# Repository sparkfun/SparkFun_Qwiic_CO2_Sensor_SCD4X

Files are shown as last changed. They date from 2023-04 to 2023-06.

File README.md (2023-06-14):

SparkFun CO₂ Humidity and Temperature Sensor - SCD4x (Qwiic)
========================================

<table class="table table-hover table-striped table-bordered">
    <tr>
        <th class="text-center">
        </th>
        <th class="text-center">
        </th>
    </tr>
    <tr align="center">
        <td><a href="https://www.sparkfun.com/products/22395">SCD40</a></td>
        <td><a href="https://www.sparkfun.com/products/22396">SCD41</a></td>
    </tr>
    <tr align="center">
        <td><a href="https://www.sparkfun.com/products/22395">SparkFun CO₂ Humidity and Temperature Sensor - SCD40 (Qwiic)</a></td>
        <td><a href="https://www.sparkfun.com/products/22396">SparkFun CO₂ Humidity and Temperature Sensor - SCD41 (Qwiic)</a></td>
    </tr>
</table>

The SparkFun CO<sub>2</sub> Humidity and Temperature Sensor - SCD4x (Qwiic) features the SCD40 and SCD41 CO<sub>2</sub> sensors from Sensirion<sup>&copy;</sup>. The SCD4x sensors use Sensirion's PASens<sup>&reg;</sup> photoacoustic measurement system that combines narrow-band IR light and a microphone inside the sensing package capable of detecting concentrations from 0 to 40000 ppm with high accuracy. The SCD40 has best accuracy over 400-2000 ppm ±(50 ppm+5%) and the SCD41 has best accuracy over 400-5000 ppm ±(40 ppm+5%). The SCD4x have an integrated temperature and humidity CMos<sup>&reg;</sup> sensor to improve accuracy. For additional accuracy the SCD4x also accept ambient pressure readings!

Repository Contents
-------------------

* **/Documentation** - Data sheets, additional product information
* **/Hardware** - Eagle design files (.brd, .sch)
* **/Production** - Production panel files (.brd)
* **/docs** - Online documentation files

Documentation
--------------
* **[SparkFun SCD4x CO<sub>2</sub> Sensor Arduino Library](https://github.com/sparkfun/SparkFun_SCD4x_Arduino_Library)** - Arduino library for the SparkFun CO₂ Humidity and Temperature Sensor - SCD4x (Qwiic).
* **[Hookup Guide](https://sparkfun.github.io/SparkFun_Qwiic_CO2_Sensor_SCD4X)** - Basic hookup guide for the SparkFun Qwiic CO<sub>2</sub> Sensor - SCD4x.
* **[SparkFun Fritzing repo](https://github.com/sparkfun/Fritzing_Parts)** - Fritzing diagrams for SparkFun products.

Product Versions
----------------
* [SEN-22935](https://www.sparkfun.com/products/22395) - Qwiic CO<sub>2</sub> Sensor - SCD40
* [SEN-22396](https://www.sparkfun.com/products/22395) - Qwiic CO<sub>2</sub> Sensor - SCD41

Version History
---------------
* [SCD40 v10](https://www.sparkfun.com/products/22395) - Initial SparkFun release (SCD40)
* [SCD41 v10](https://www.sparkfun.com/products/22396) - Initial SparkFun release (SCD41)
* [SparkX SCD40 v01](https://www.sparkfun.com/products/18365) - Initial SparkX release (SCD40)
* [SparkX SCD41 v01](https://www.sparkfun.com/products/18366) - Initial SparkX release (SCD41)

License Information
-------------------

This product is _**open source**_!

Please review the LICENSE.md file for license information.

If you have any questions or concerns on licensing, please contact technical support on our [SparkFun forums](https://forum.sparkfun.com/viewforum.php?f=152).

Distributed as-is; no warranty is given.

- Your friends at SparkFun.

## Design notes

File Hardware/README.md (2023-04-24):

SparkFun <PRODUCT NAME> Design Files
=====================================

The .sch and .brd files hare are Eagle CAD schematic and PCB design files from SparkFun Electronics.
A freeware version of Autodesk Eagle can be found [here](https://www.autodesk.com/products/eagle/free-download).

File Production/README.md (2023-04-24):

SparkFun <PRODUCT NAME> Production Files
=========================================

These are the production files SparkFun uses for printing PCBs.

License Information
-------------------
This product is open source! 

The hardware is released under [Creative Commons ShareAlike 4.0 International](https://creativecommons.org/licenses/by-sa/4.0/).

Please use, reuse, and modify these files as you see fit. Please maintain attribution to SparkFun Electronics and release anything derivative under the same license.

Distributed as-is; no warranty is given.

- Your friends at SparkFun.

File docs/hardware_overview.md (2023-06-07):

---
icon: material/cog
---

Let's take a closer look at the SCD4X sensors and hardware on these sensor breakouts.

## SCD40 and SCD41 CO<sub>2</sub> Sensors

The SCD4x CO<sub>2</sub> sensors use Sensirion's PASense<sup>&trade;</sup>, a photoacoustic measurement system, to accurately measure CO<sub>2</sub> concentration using a combination of a narrow band of IR light and a microphone. The sensors also have a built-in humidity and temperatuer sensor using Sensirion's CMOSens<sup>&trade;</sup> technology to provide environmental data and compensate for environmental conditions in CO<sub>2</sub> measurement. For a detailed overview of the SCD4X sensors, refer to the [datasheet](./assets/component_documentation/Sensirion_CO2_Sensors_SCD4x_Datasheet.pdf).

<figure markdown>
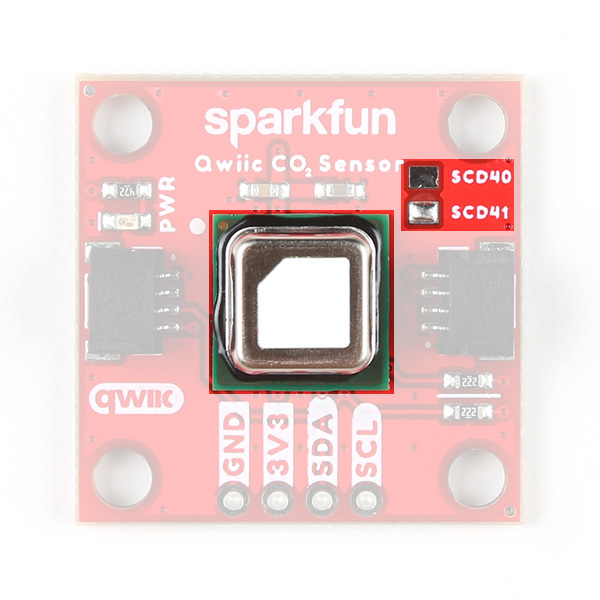
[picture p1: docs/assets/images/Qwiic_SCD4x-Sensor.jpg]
Highlighting the SCD4x sensor and version indicator

<figcaption markdown>Note: The PCB design is shared between the SCD40 and SCD41 and the version is indicated by the solder pad above the sensor.</figcaption>
</figure>

Now you may be curious as to just what photoacoustic measuring actually is. Photoacoustic measuring uses light (photo) and sound/vibrations (acoustic) in tandem to measure the the photoacoustic effect when energy is absorbed by particles (in the case of these sensors, CO<sub>2</sub> molecules). The SCD4X has an IR emitter with a filter to shine a specific IR light into the sensing area. CO<sub>2</sub> molecules inside the sensing area absorb energy from the emitted IR light and vibrate. The microphone inside the sensing area picks up this acoustic vibration and then this data is processed to report CO<sub>2</sub> concentration. This is just a quick and basic explanation of the photoacoustic process used in these sensors. For detailed information on Sensirion's PASens and CMOSens technology, refer to their [technology page](https://sensirion.com/products/technology).

The SCD4X sensors accept a supply voltage between <b>2.4V</b> to <b>5.5V</b> though they run on <b>3.3V</b> in standard Qwiic circuits. The sensors draw max of <b>205mA@3.3V</b> with an average draw of <b>18mA@3.3V</b> with periodic measurements in normal mode (<b>3.5mA@3.3V</b> in low power mode). While in Single Shot mode and taking one measurement every five minutes, the SCD41 draws only <b>0.5mA@3.3V</b>. 

Both sensors have identical operating characteristics outside of their ideal measurement ranges, measurement accuracy, and feature set. The SCD40's ideal measurement range is 400ppm to 2,000pm with an accuracy of &plusmn;50ppm + 5% of the reading and the SCD41 has an ideal measurement range of 400ppm to 5,000ppm with an accuracy of &plusmn;40ppm + 5% of the reading. The SCD41 also includes a single-shot mode for low power applications. The table below outlines the rest of the SCD4X's sensing parameters: 

<table>
    <tr>
        <th>Parameter</th>
        <th>Units</th>
        <th>Min</th>
        <th>Typ</th>
        <th>Max</th>
        <th>Notes</th>
    </tr>
    <tr>
        <td>CO<sub>2</sub> Output Range</td>
        <td>ppm</td>
        <td>0</td>
        <td>-</td>
        <td>40,000</td>
        <td></td>
    </tr>
    <tr>
        <td rowspan="2" style="vertical align middle">CO<sub>2</sub> Measurement Accuracy</td>
        <td rowspan="2" style="vertical align middle">ppm</td>
        <td>-</td>
        <td>&plusmn;(50 + 5%)</td>
        <td>-</td>
        <td>SCD40 accuracy</td>
    </tr>
    <tr>
        <td>-</td>
        <td>&plusmn;(40 + 5%)</td>
        <td>-</td>
        <td>SCD41 accuracy</td>
    </tr>
    <tr>
        <td>Humidity Range</td>
        <td>%RH</td>
        <td>0</td>
        <td>-</td>
        <td>100</td>
        <td></td>
    </tr>
    <tr>
        <td rowspan="2" style="vertical align middle">Humidity Accuracy</td>
        <td rowspan="2" style="vertical align middle">%RH</td>
        <td>-</td>
        <td>&plusmn;6</td>
        <td>-</td>
        <td>15&deg;C - 35&deg;C, 20%RH - 65%RH</td>
    </tr>
    <tr>
        <td>-</td>
        <td>&plusmn;9</td>
        <td>-</td>
        <td>-10&deg;C - 60 &deg;C, 0%RH - 100%RH</td>
    </tr>
    <tr>
        <td>Temperature Range</td>
        <td>&deg;C</td>
        <td>-10</td>
        <td>-</td>
        <td>60</td>
        <td></td>
    </tr>
    <tr>
        <td rowspan="2" style="vertical align middle">Temperature Accuracy</td>
        <td rowspan="2" style="vertical align middle">&deg;C</td>
        <td>-</td>
        <td>&plusmn;0.8</td>
        <td>-</td>
        <td>15&deg;C - 35&deg;C</td>
    </tr>
    <tr>
        <td>-</td>
        <td>&plusmn;1.5</td>
        <td>-</td>
        <td>-10&deg;C - 60&deg;C</td>
    </tr>
</table>

## Qwiic/I<sup>2</sup>C Interface

The boards route the SCD4X's I<sup>2</sup>C interface to a pair of Qwiic connectors as well as a 0.1"-spaced plated through-hole (PTH) header.

<figure markdown>
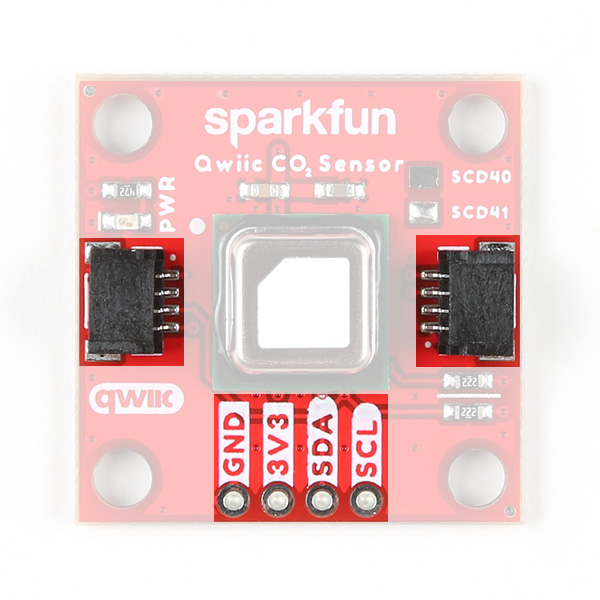
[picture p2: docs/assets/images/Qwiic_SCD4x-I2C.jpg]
Highlighting the Qwiic connectors and I2C PTH header.

</figure>

The SDC4X's has a 7-bit unshifted address of <b>0x62</b>. The I<sup>2</sup>C bus has a start up time after hard and soft resets of 1000ms and supports clock speeds up to 100kHz.

## LED

The sole LED on these boards is a red Power LED indicating when power is supplied to the board.

<figure markdown>
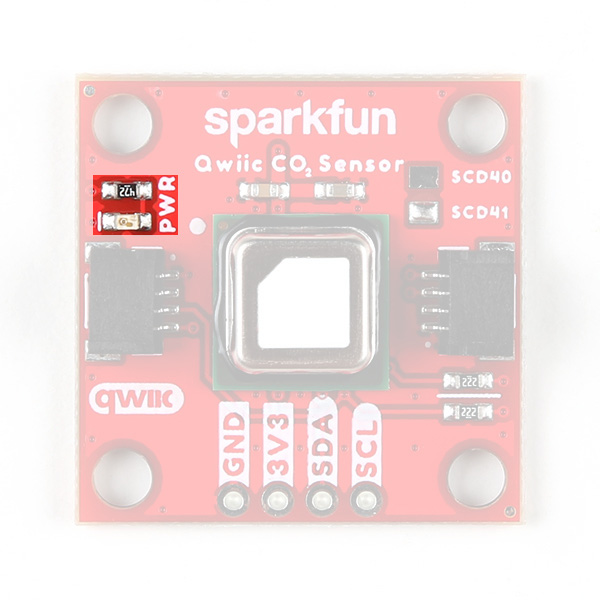
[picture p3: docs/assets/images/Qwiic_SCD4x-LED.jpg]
Highlighting the power LED

</figure>

## Solder Jumpers

The breakouts have a pair of solder jumpers labeled <b>PWR</b> and <b>I2C</b>. The PWR jumper completes the Power LED circuit. Open the jumper to disable the Power LED and reduce current draw of the board. The I2C jumper pulls the SDA/SCL lines to VCC (typically <b>3.3V</b>) through a pair of 2.2k&ohm; resistors. Open the jumper to disable the pullup resistors if needed.

<figure markdown>
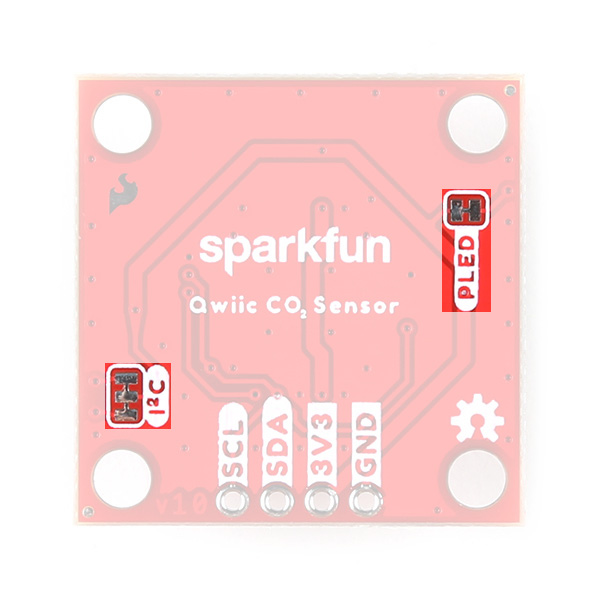
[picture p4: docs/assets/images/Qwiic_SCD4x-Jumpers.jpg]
Highlighting the solder jumpers

</figure>

## Board Dimensions

These breakouts match the 1" x 1" (25.4mm x 25.4mm) Qwiic breakout standard and have four mounting holes that fit a [4-40 screw](https://www.sparkfun.com/products/10453).

<figure markdown>
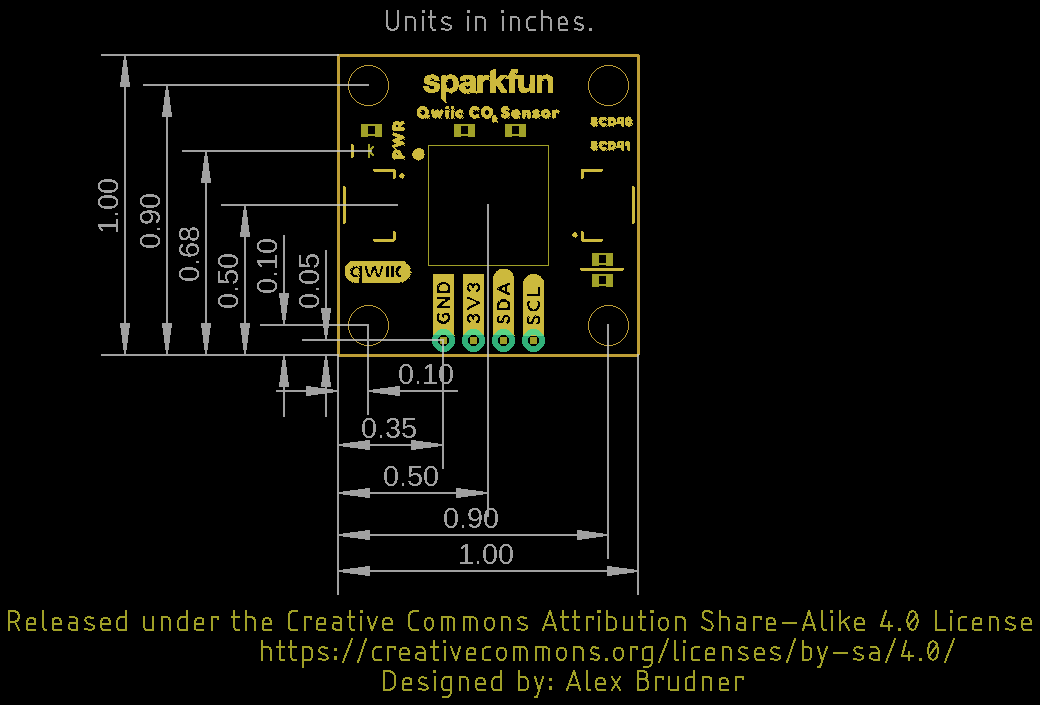
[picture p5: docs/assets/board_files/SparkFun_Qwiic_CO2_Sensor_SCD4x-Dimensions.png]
Board Dimensions

</figure>

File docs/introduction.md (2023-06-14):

---
icon: material/book-open-page-variant
---

The SparkFun CO<sub>2</sub>, Humidity and Temperature Sensor - SCD4X (Qwiic) breakouts feature the SCD40 and SCD41 CO<sub>2</sub> sensors from Sensirion<sup>&trade;</sup>. The SCD4X sensors use Sensirion&apos;s PASens<sup>&trade;</sup> photoacoustic measurement system that combines the use of narrow-band IR light and a microphone inside the sensing package that results in a high-quality sensor that measures CO<sub>2</sub> concentrations from 0 to 40,000ppm. The sensors also have an integrated humidity and temperature sensor to provide environmental conditions to improve accuracy. The SCD40 has the best accuracy from 400 to 2,000ppm and the SCD41 has the best accuracy from 400 to 5,000ppm.

These sensors also feature automatic self-calibration routines to automatically adjust to their sensing environments over seven day calibration period. For best results, Sensirion recommends taking continuous readings for at least one hour a day of 'fresh air' for the calibration period to complete.

<section class="grid cards col-2"markdown>

-	<a href="https://www.sparkfun.com/products/22395">
    <figure markdown>
	Product image
	</figure>
    </a>

    ---

    <a href="https://www.sparkfun.com/products/22395">
	**SparkFun CO<sub>2</sub> Humidity and Temperature Sensor - SCD40 (Qwiic)**<br>
	**SKU:** SEN-22395 
    </a>
	<center>
    [Purchase from SparkFun :fontawesome-solid-cart-plus:](https://www.sparkfun.com/products/22395){ .md-button .md-button--primary }
    </center>
    
-	<a href="https://www.sparkfun.com/products/22396">
    <figure markdown>
	Product image
	</figure>
    </a>

    ---

    <a href="https://www.sparkfun.com/products/22396">
    **SparkFun CO<sub>2</sub> Humidity and Temperature Sensor - SCD41 (Qwiic)**<br>
	**SKU:** SEN-22396
    </a>
	<center>
	[Purchase from SparkFun :fontawesome-solid-cart-plus:](https://www.sparkfun.com/products/22396){ .md-button .md-button--primary }
	</center>
    
</section>

<div style="text-align: center;">
    <iframe width="560" height="315" src="https://www.youtube.com/embed/sJqToow_iAg" title="YouTube video player" frameborder="0" allow="accelerometer; autoplay; clipboard-write; encrypted-media; gyroscope; picture-in-picture; web-share" allowfullscreen>
    </iframe>
</div>

In this guide we'll go over the details of the SCD4x sensors and other hardware present on these breakout boards, how to assemble it into a Qwiic circuit and how to use it with the SparkFun SCD4x Arduino Library.

## Required Materials

To follow along with this guide you will need a microcontroller to communicate with these SCD4X breakouts. Below are a few options that come Qwiic-enabled out of the box:

<div class="grid cards" markdown>

-   <a href="https://www.sparkfun.com/products/20168">

    <figure markdown>
    SparkFun Thing Plus - ESP32 WROOM (USB-C)
    </figure>
    </a>
    ---
    <a href="https://www.sparkfun.com/products/20168">
    **SparkFun Thing Plus - ESP32 WROOM (USB-C)**<br>
    DEV-20168
    </a>

-   <a href="https://www.sparkfun.com/products/18158">
    
    <figure markdown>
    SparkFun RedBoard Plus
    </figure>
    </a>
    ---
    <a href="https://www.sparkfun.com/products/18158">
    **SparkFun RedBoard Plus**<br>
    DEV-18158
    </a>

-   <a href="https://www.sparkfun.com/products/15574">
    
    <figure markdown>
    SparkFun Thing Plus - Artemis
    </figure>
    </a>
    ---
    <a href="https://www.sparkfun.com/products/15574">
    **SparkFun Thing Plus - Artemis**<br>
    DEV-18158
    </a>

-   <a href="https://www.sparkfun.com/products/15444">

    <figure markdown>
    SparkFun RedBoard Artemis
    </figure>
    </a>
    ---
    <a href="https://www.sparkfun.com/products/15444">**SparkFun RedBoard Artemis**<br>
    DEV-15444
    </a>
</div>

If your chosen microcontroller is not already Qwiic-enabled, you can add that functionality with one or more of the following items:

<div class="grid cards" markdown>

-   <a href="https://www.sparkfun.com/products/15081">

    <figure markdown>
    SparkFun Qwiic Cable Kit
    </figure>
    </a>
    ---
    <a href="https://www.sparkfun.com/products/15081">
    **SparkFun Qwiic Cable Kit**<br>
    KIT-15081
    </a>

-   <a href="https://www.sparkfun.com/products/14495">
    
    <figure markdown>
    SparkFun Qwiic Adapter
    </figure>
    </a>
    ---
    <a href="https://www.sparkfun.com/products/14495">
    **SparkFun Qwiic Adapter**<br>
    DEV-14495
    </a>

-   <a href="https://www.sparkfun.com/products/14352">
    
    <figure markdown>
    SparkFun Qwiic Shield for Arduino
    </figure>
    </a>
    ---
    <a href="https://www.sparkfun.com/products/14352">
    **SparkFun Qwiic Shield for Arduino**<br>
    DEV-14352
    </a>

-   <a href="https://www.sparkfun.com/products/16790">

    <figure markdown>
    SparkFun Qwiic Shield for Thing Plus
    </figure>
    </a>
    ---
    <a href="https://www.sparkfun.com/products/16790">
    **SparkFun Qwiic Shield for Thing Plus**<br>
    DEV-16790
    </a>
</div>

You will also need at least one Qwiic cable to connect your SCD4X breakout to your microcontroller:

<div class="grid cards" markdown>

-   <a href="https://www.sparkfun.com/products/17259">

    <figure markdown>
    Flexible Qwiic Cable - 100mm)
    </figure>
    </a>
    ---
    <a href="https://www.sparkfun.com/products/17259">
    **Flexible Qwiic Cable - 100mm**<br>
    PRT-17259
    </a>

-   <a href="https://www.sparkfun.com/products/17260">
    
    <figure markdown>
    Qwiic Cable - 50mm
    </figure>
    </a>
    ---
    <a href="https://www.sparkfun.com/products/17260">
    **Flexible Qwiic Cable - 50mm**<br>
    PRT-17260
    </a>

-   <a href="https://www.sparkfun.com/products/17257">
    
    <figure markdown>
    Flexible Qwiic Cable - 500mm
    </figure>
    </a>
    ---
    <a href="https://www.sparkfun.com/products/17257">
    **Flexible Qwiic Cable - 500mm**<br>
    PRT-17257
    </a>

-   <a href="https://www.sparkfun.com/products/17261">

    <figure markdown>
    Flexible Qwiic Cable - Female Jumper (4-pin)
    </figure>
    </a>
    ---
    <a href="https://www.sparkfun.com/products/17261">**Flexible Qwiic Cable - Female Jumper (4-pin)**<br>
    CAB-17261
    </a>
</div>

## Optional Materials

If you prefer a soldered connection or want to modify the solder jumpers on this board, you may need some of the products listed below:

<div class="grid cards" markdown align="center">

-   <a href="https://www.sparkfun.com/products/116">

    <figure markdown>
    Break Away Headers - Straight)
    </figure>
    </a>
    ---
    <a href="https://www.sparkfun.com/products/116">
    **Break Away Headers - Straight**<br>
    PRT-00116
    </a>

-   <a href="https://www.sparkfun.com/products/14681">
    
    <figure markdown>
    SparkFun Beginner Tool Kit
    </figure>
    </a>
    ---
    <a href="https://www.sparkfun.com/products/14681">
    **SparkFun Beginner Tool Kit**<br>
    TOL-14681
    </a>

-   <a href="https://www.sparkfun.com/products/9200">
    
    <figure markdown>
    Hobby Knife
    </figure>
    </a>
    ---
    <a href="https://www.sparkfun.com/products/9200">
    **Hobby Knife**<br>
    TOL-09200
    </a>

-   <a href="https://www.sparkfun.com/products/14579">

    <figure markdown>
    Chip Quik No-Clean Flux Pen - 10mL
    </figure>
    </a>
    ---
    <a href="https://www.sparkfun.com/products/14579">**Chip Quik No-Clean Flux Pen - 10mL**<br>
    CAB-14579
    </a>
</div>

## Suggested Reading

We designed this board for integration into SparkFun's Qwiic connect system.  Click on the banner below to learn more about the [SparkFun Qwiic Connect System](https://www.sparkfun.com/qwiic).

<div style="text-align: center">
<table>
  <tr>
   <td>
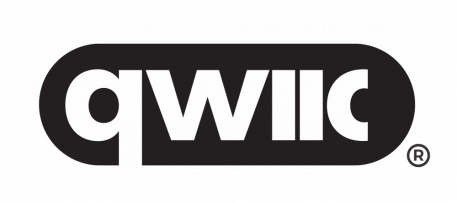
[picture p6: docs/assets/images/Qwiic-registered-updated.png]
Qwiic Connect System Click to learn more about the Qwiic Connect System!
   <div style="text-align: center"></div>
   </td>
  </tr>
  <tr>
    <td><div style="text-align: center"><i><a href="https://www.sparkfun.com/qwiic">Qwiic Connect System</a></i></div></td>
  </tr>
</table>
</div>

Before getting started with this Hookup Guide, you may want to read through the tutorials below if you are not familiar with the concepts covered in them or want a refresher. If you are using either of the Qwiic Shields linked above, we recommend reading through their respective Hookup Guides before continuing with this tutorial:

<div class="grid cards hide col-4" markdown align="center">

-   <a href="https://learn.sparkfun.com/tutorials/8">
    <figure markdown>
    Serial Communication
    </figure>
    </a>
    <a href="https://learn.sparkfun.com/tutorials/8">**Serial Communication**
    </a>

-   <a href="https://learn.sparkfun.com/tutorials/82">
    <figure markdown>
    I2C
    </figure>
    </a>
    <a href="https://learn.sparkfun.com/tutorials/82">**I2C**
    </a>

-   <a href="https://learn.sparkfun.com/tutorials/62">
    <figure markdown>
    Logic Levels
    </figure>
    </a>
    <a href="https://learn.sparkfun.com/tutorials/62">**Logic Levels**
    </a>

-   <a href="https://learn.sparkfun.com/tutorials/61">
    <figure markdown>
    Installing Arduino IDE
    </figure>
    </a>
    <a href="https://learn.sparkfun.com/tutorials/61">**Installing Arduino IDE**
    </a>

-   <a href="https://learn.sparkfun.com/tutorials/15">
    <figure markdown>
    Installing an Arduino Library
    </figure>
    </a>
    <a href="https://learn.sparkfun.com/tutorials/15">**Installing an Arduino Library**
    </a>

-   <a href="https://learn.sparkfun.com/tutorials/112">
    <figure markdown>
    Serial Terminal Basics
    </figure>
    </a>
    <a href="https://learn.sparkfun.com/tutorials/112">**Serial Terminal Basics**
    </a>

-   <a href="https://learn.sparkfun.com/tutorials/664">
    <figure markdown>
    How to Work with Jumper Pads and PCB Traces
    </figure>
    </a>
    <a href="https://learn.sparkfun.com/tutorials/664">**How to Work with Jumper Pads and PCB Traces**
    </a>

-   <a href="https://learn.sparkfun.com/tutorials/684">
    <figure markdown>
    Qwiic Shield for Arduino & Photon Hookup Guide
    </figure>
    </a>
    <a href="https://learn.sparkfun.com/tutorials/684">**Qwiic Shield for Arduino & Photon Hookup Guide**
    </a>

-   <a href="https://learn.sparkfun.com/tutorials/1107">
    <figure markdown>
    Qwiic Shield for Thing Plus Hookup Guide
    </figure>
    </a>
    <a href="https://learn.sparkfun.com/tutorials/1107">**Qwiic Shield for Thing Plus Hookup Guide**
    </a>
</div>

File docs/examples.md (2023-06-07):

The SparkFun SCD4X Arduino Library includes several examples to start receiving CO<sub>2</sub> concentration, temperature and humidity data from the SCD4X. Let's take a closer look at a few of the examples included with the library.

## Example 1 - Basic Readings

The first example in the library demonstrates how to initialize the SCD4X on the I<sup>2</sup>C bus to poll data from the sensor using periodic measurements every five seconds. Open the example by navigating to **File** > **Examples** > **SparkFun SCD4x Arduino Library** > **Example1_BasicReadings**. Alternatively, you can copy the code below into a blank Arduino sketch:

??? "Example 1 Arduino Code"
	```
	--8<-- "https://raw.githubusercontent.com/sparkfun/SparkFun_SCD4x_Arduino_Library/main/examples/Example1_BasicReadings/Example1_BasicReadings.ino"
	```

Select your Board/Port and click the "Upload" button. Once the code finishes uploading, open up a [Serial Monitor](https://learn.sparkfun.com/tutorials/terminal-basics) and check the output. You should see CO<sub>2</sub>, temperature and humidity data print out every 5 seconds:

<figure markdown>
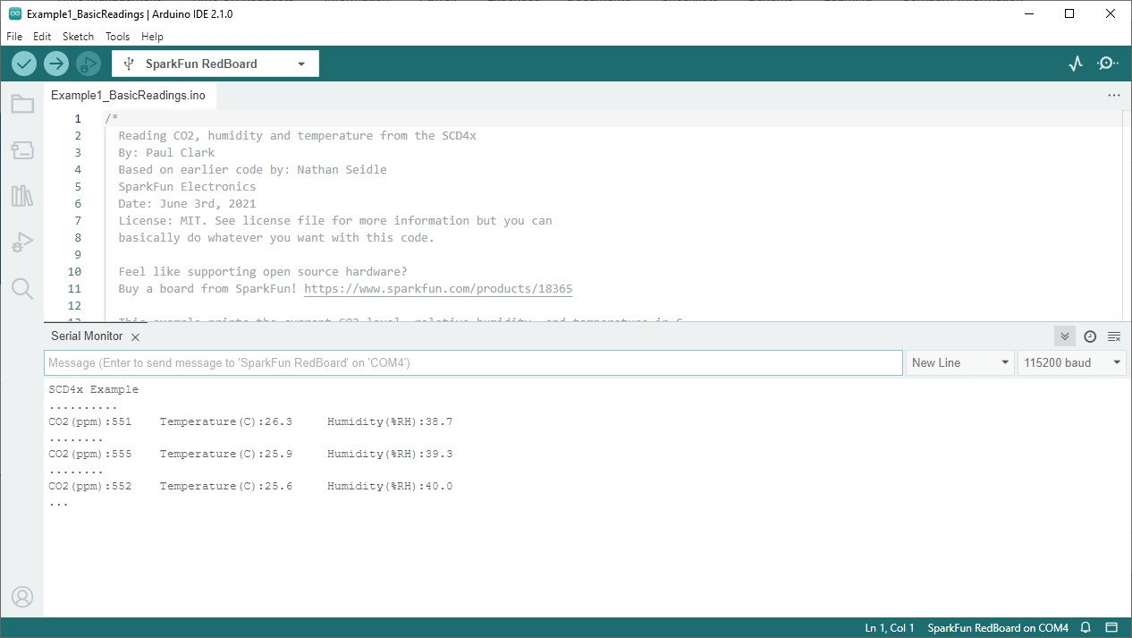
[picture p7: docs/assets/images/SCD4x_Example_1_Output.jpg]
Highlighting the power LED

</figure>

## Example 2 - Low Power Readings

The second example demonstrates how to configure the SCD4X to disable periodic measurements and enable low-power mode. This sets the SCD4x to take measurements every 30 seconds. Open the example in Arduino or copy the code below into a blank sketch:

??? "Example 2 Arduino Code"
    ```
	--8<-- "https://raw.githubusercontent.com/sparkfun/SparkFun_SCD4x_Arduino_Library/main/examples/Example2_LowPowerReadings/Example2_LowPowerReadings.ino"
	```
After uploading, open the serial monitor and you should see data print out every second though it should remain static for the 30 seconds between measurements.

## Example 6 - Signal Compensation

Example six shows how to input custom compensation values for temperature, altitude and ambient pressure. The code stops periodic measurements while the values are stored. These values are stored in the sensor's RAM by default but can be stored in EEPROM. When stored in RAM, the values reset if <code>reInit</code> is called or on a power cycle. After the settings are stored, the code reinitializes periodic measurements and prints out data for CO<sub>2</sub>, temperature, and humidity.

??? "Example 6 Arduino Code"
    ```
	--8<-- "https://raw.githubusercontent.com/sparkfun/SparkFun_SCD4x_Arduino_Library/main/examples/Example6_SignalCompensation/Example6_SignalCompensation.ino"
	```

## Example 8 - SCD41 Single Shot

The eighth example demonstrates how to configure the SCD41 to operate in Single-Shot mode for maximum power efficiency. The code disables periodic measurements and enables single-shot measurements with the <code>measureSingleShot</code> function. The main loop waits for fresh data from the SCD41 and then prints out CO<sub>2</sub>, temperature, and humidity data whenever it is available.

??? "Example 6 Arduino Code"
    ```
	--8<-- "https://raw.githubusercontent.com/sparkfun/SparkFun_SCD4x_Arduino_Library/main/examples/Example8_SCD41SingleShot/Example8_SCD41SingleShot.ino"
	```

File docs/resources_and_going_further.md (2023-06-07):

For more information about the SCD4X and these breakouts, check out the links below:

* Schematics:
    * [SCD40](./assets/board_files/SparkFun_Qwiic_CO2_Sensor_SCD40.pdf)
    * [SCD41](./assets/board_files/SparkFun_Qwiic_CO2_Sensor_SCD41.pdf)
* Eagle Files:
    * [SCD40](./assets/board_files/SparkFun_Qwiic_CO2_Sensor_SCD40.zip)
    * [SCD41](./assets/board_files/SparkFun_Qwiic_CO2_Sensor_SCD41.zip)
* [Board Dimensions](./assets/board_files/SparkFun_Qwiic_CO2_Sensor_SCD4x-Dimensions.png)
* [Datasheet](./assets/component_documentation/Sensirion_CO2_Sensors_SCD4x_Datasheet.pdf) (SCD4X)
* [Qwiic Info Page](https://www.sparkfun.com/qwiic)
* [SparkFun SCD4X Arduino Library](https://github.com/sparkfun/SparkFun_SCD4x_Arduino_Library)
* [Hardware GitHub Repo](https://github.com/sparkfun/SparkFun_Qwiic_CO2_Sensor_SCD4X)

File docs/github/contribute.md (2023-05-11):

# Help Improve the Experience!
Spot an improvement opportunity? Feel free to contribute to our open-source design and documentation. 

## Enhance our Documentation
All of this documentation can be modified by you! Please help us make it better.

* These pages are contained in the [`docs` folder](https://github.com/sparkfun/SparkFun_Qwiic_CO2_Sensor_SCD4X/tree/main/docs) of the [SparkFun Qwiic CO<sub>2</sub> Sensor - SCD4X](https://github.com/sparkfun/SparkFun_Qwiic_CO2_Sensor_SCD4X) repository.

### Submit a Correction
1. Fork this repo
2. Add your corrections or improvements to the markdown file
3. File a pull request with your changes, and enjoy making the ~~words~~ ~~worlds~~ world a better place.
	* Once received, the documentation specialist will automatically be notified.
	* We will review your suggested improvements to make sure they are correct and fit within our documentation standards.

## Upgrade our Hardware Design
All of our designs are open-source! Please help us make it better.

* Our board design files are contained in the [`Hardware` folder](https://github.com/sparkfun/SparkFun_Qwiic_CO2_Sensor_SCD4X/tree/main/Hardware) of the [SparkFun Qwiic CO<sub>2</sub> Sensor - SCD4X](https://github.com/sparkfun/SparkFun_Qwiic_CO2_Sensor_SCD4X) repository.

### Submit a Design Improvement
1. Fork this repo
2. Add your design modifications
3. File a pull request with your changes, and enjoy making the world a better place.
	* Once received, the engineer in charge of the original design will automatically be notified.
	* We will review your suggested upgrades, if they are within our board design standards and meet our product design requirements, we will flag these changes for our next board revision.
	
	!!! note
		Please note, that even if your suggestion is accepted, these changes may not be immediate. We may have to cycle through our current product inventory first.

## Contributors
Let's provide some recognition to those who have contributed to this project!

GitHub Contributors Image
<br>


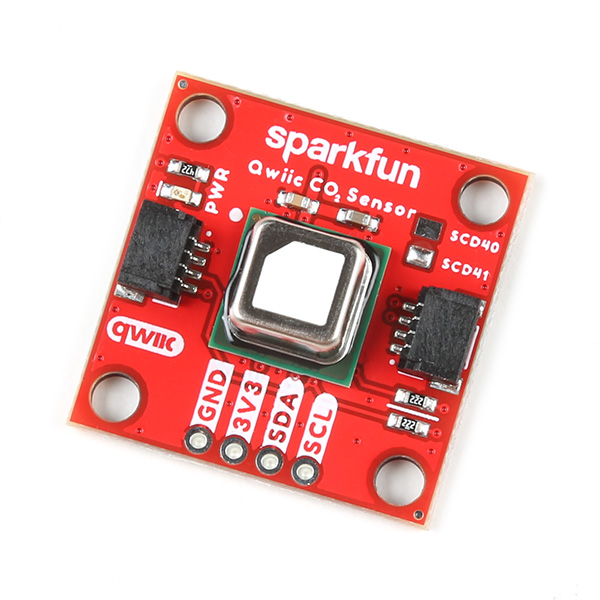
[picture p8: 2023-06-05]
site/assets/images/Qwiic_SCD4x-Thumb.jpg

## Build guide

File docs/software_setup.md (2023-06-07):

---
icon: simple/arduino
---

!!! attention
	If this is your first time using Arduino, please read through our tutorial on [installing the Arduino IDE](https://learn.sparkfun.com/tutorials/installing-arduino-ide). If you have not installed an Arduino library before, we recommend you check out our [installation guide](https://learn.sparkfun.com/tutorials/installing-an-arduino-library).

We've written an Arduino library for the SCD4X sensors to make it easy to get CO<sub>2</sub> data from these sensors along with other settings and features for these breakouts. Users can download the library through the Arduino Library Manager by searching for <b>"SparkFun SCD4x"</b> like the screenshot below shows:

<figure markdown>
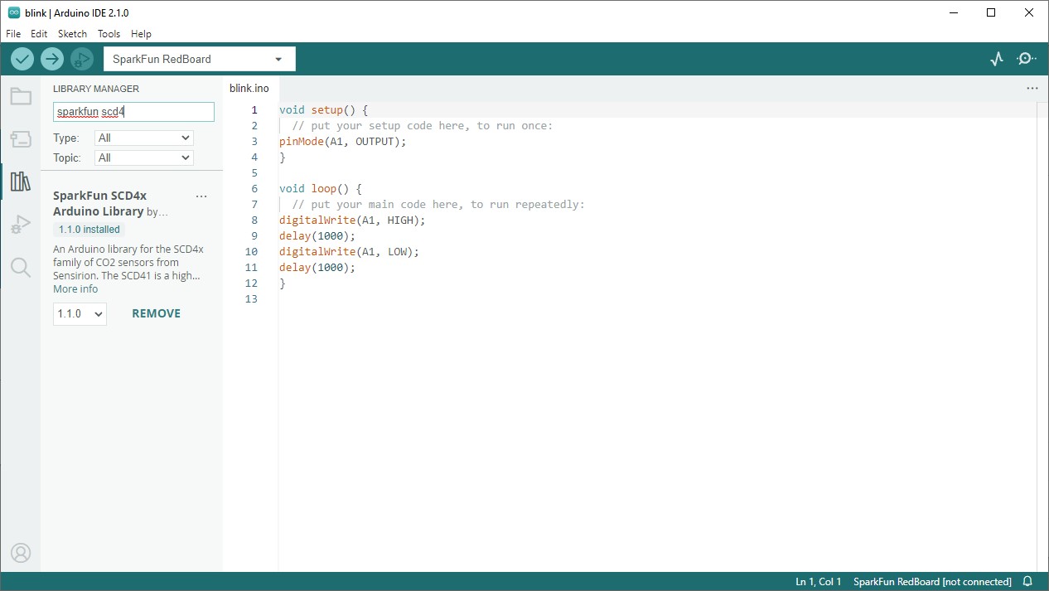
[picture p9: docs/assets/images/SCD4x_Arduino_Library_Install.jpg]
Highlighting the power LED

</figure>

Those who prefer to manually install it can download a ZIP of the library by clicking the button below:

<center>
[SparkFun SCD4x Arduino Library (ZIP)](https://github.com/sparkfun/SparkFun_SCD4x_Arduino_Library/archive/refs/heads/main.zip){ .md-button .md-button--primary }
</center>

With the library installed let's move on to looking at a few of the examples included in it.

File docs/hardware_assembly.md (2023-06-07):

---
icon: material/tools
---

Now that we're familiar with the SCD4X sensors and these breakouts, it's time to assemble it into a circuit.

## Qwiic Assembly

SparkFun's Qwiic system makes assembling a circuit a breeze. Simply plug the breakout into your chosen microcontroller with a Qwiic cable. After assembling your circuit, it should look similar to the photo below:

<figure markdown>
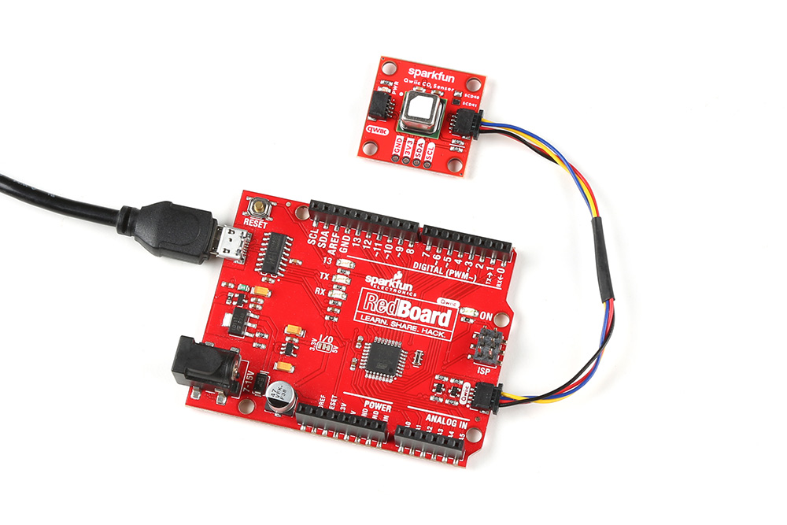
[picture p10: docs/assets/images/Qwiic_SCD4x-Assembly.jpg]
SparkFun SCD40 plugged into the RedBoard Qwiic

<figcaption markdown>SparkFun CO<sub>2</sub> Humidity and Temperature Sensor - SCD40 (Qwiic) plugged into the RedBoard Qwiic</figcaption>
</figure>

Reminder, for ideal results, make sure to fully calibrate the SCD4X by taking continuous measurements for one hour every day for seven days.

## Soldered Assembly

Those who prefer a traditional soldered assembly should solder wires or header pins to the PTH header on the side of the board. If you're not familiar with through-hole soldering or would like a refresher, take a look at our Through-Hole Soldering Tutorial:

<div class="grid cards" markdown align="center">

-   <a href="https://learn.sparkfun.com/tutorials/5">
    <figure markdown>
    How to Solder: Through-Hole Soldering
    </figure>
    </a>
    <a href="https://learn.sparkfun.com/tutorials/5">**How to Solder: Through-Hole Soldering**
    </a>

</div>

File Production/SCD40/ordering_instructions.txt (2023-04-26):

panel size, 169x117mm
PCB thickness, 1.6mm
number of layers, 2
soldermask color, Red
silkscreen color, White
oz copper, 1oz
finish, HASL lead free
stencils, top
pcs per panel, 24
min trace width, 0.1270mm / 0.0050in
min drill size, 0.3810mm / 0.0150in

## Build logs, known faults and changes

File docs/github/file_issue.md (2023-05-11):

# Did we make a mistake?

Spot something wrong? Please let us know. 

!!! attention
	This is not where customers should seek assistance on a product. If you require technical assistance or have questions about a product that is not working as expected, please head over to the [SparkFun Technical Assistance](https://www.sparkfun.com/technical_assistance) page for some initial troubleshooting.
    <center>
    [SparkFun Technical Assistance Page](https://www.sparkfun.com/technical_assistance){ .md-button .md-button--primary }
    </center>
    
    If you can't find what you need there, the [SparkFun Forums](https://forum.sparkfun.com/index.php) is a great place to search product forums and ask questions.
    
    !!! info "Account Registration Required"
        If this is your first visit to our forum, you'll need to create a [Forum Account](https://forum.sparkfun.com/ucp.php?mode=register) to search product forums and post questions.

## Discrepancies in the Documentation

All of this documentation can be modified by you! Please help us make it better.

* The documentation files for these pages are contained in the [`docs` folder](https://github.com/sparkfun/SparkFun_Qwiic_CO2_Sensor_SCD4X/tree/main/docs) of the [SparkFun Qwiic CO<sub>2</sub> Sensor - SCD4X](https://github.com/sparkfun/SparkFun_Qwiic_CO2_Sensor_SCD4X) repository.

### Spot something wrong?
If a section of the documentation is incorrect, please [open an issue](https://github.com/sparkfun/SparkFun_Qwiic_CO2_Sensor_SCD4X/issues) and let us know.

### Do you have a suggested correction?
1. With a GitHub account, fork this repo
2. Add your correction(s) or improvement(s) to the markdown file(s)
3. File a pull request with your changes, and enjoy making the ~~words~~ ~~worlds~~ world a better place.
	* Once received, the documentation specialist will automatically be notified.
	* We will review your suggested improvement(s) to make sure they are correct and fit within our documentation standards.

## Problems in the Hardware Design

All of our designs are open-source! Please help us make it better.

* Our board design files are contained in the [`Hardware` folder](https://github.com/sparkfun/SparkFun_Qwiic_CO2_Sensor_SCD4X/tree/main/Hardware) of the [SparkFun Qwiic CO<sub>2</sub> Sensor - SCD4X](https://github.com/sparkfun/SparkFun_Qwiic_CO2_Sensor_SCD4X) repository.

### Does something not make sense?
If part of the design is confusing, please [open an issue](https://github.com/sparkfun/SparkFun_Qwiic_CO2_Sensor_SCD4X/issues) and let us know.

### Did we forget to include an important function of the board?
* Please keep in mind that we may intentionally exclude certain functions of the board to meet our product design requirements. *(For example, our Qwiic Micro boards are intended to fit on a small board layout and only use I<sup>2</sup>C communication; therefore, we may not have the SPI and interrupt pins available for users.)*
* If part of the board's functionality is missing, please [open an issue](https://github.com/sparkfun/SparkFun_Qwiic_CO2_Sensor_SCD4X/issues) and file a feature request.

### Do you wish to contribute directly to improving the board design?
1. With a GitHub account, Fork this repo
2. Add your design improvement(s)
3. File a pull request with your changes, and enjoy making the ~~words~~ ~~worlds~~ world a better place.
	* Once received, the engineer in charge of the original design will automatically be notified.
	* We will review your suggested improvement(s), if they are within our board design standards and meet our product design requirements, we will flag these changes for our next board revision. *(Please note, that even if your suggestion is accepted, these changes may not be immediate. We may have to cycle through our current product inventory first.)*

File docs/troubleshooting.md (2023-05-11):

!!! warning "Need Help?"
    If you need technical assistance or more information on a product that is not working as you expected, we recommend heading on over to the [SparkFun Technical Assistance](https://www.sparkfun.com/technical_assistanc) page for some initial troubleshooting.

    <center>
    [SparkFun Technical Assistance Page](https://www.sparkfun.com/technical_assistance){ .md-button .md-button--primary }
    </center>
    
    If you can't find what you need there, the [SparkFun Forums](https://forum.sparkfun.com/index.php) is a great place to search product forums and ask questions.
    
    !!! info "Account Registration Required"
        If this is your first visit to our forum, you'll need to create a [Forum Account](https://forum.sparkfun.com/ucp.php?mode=register) to post questions.

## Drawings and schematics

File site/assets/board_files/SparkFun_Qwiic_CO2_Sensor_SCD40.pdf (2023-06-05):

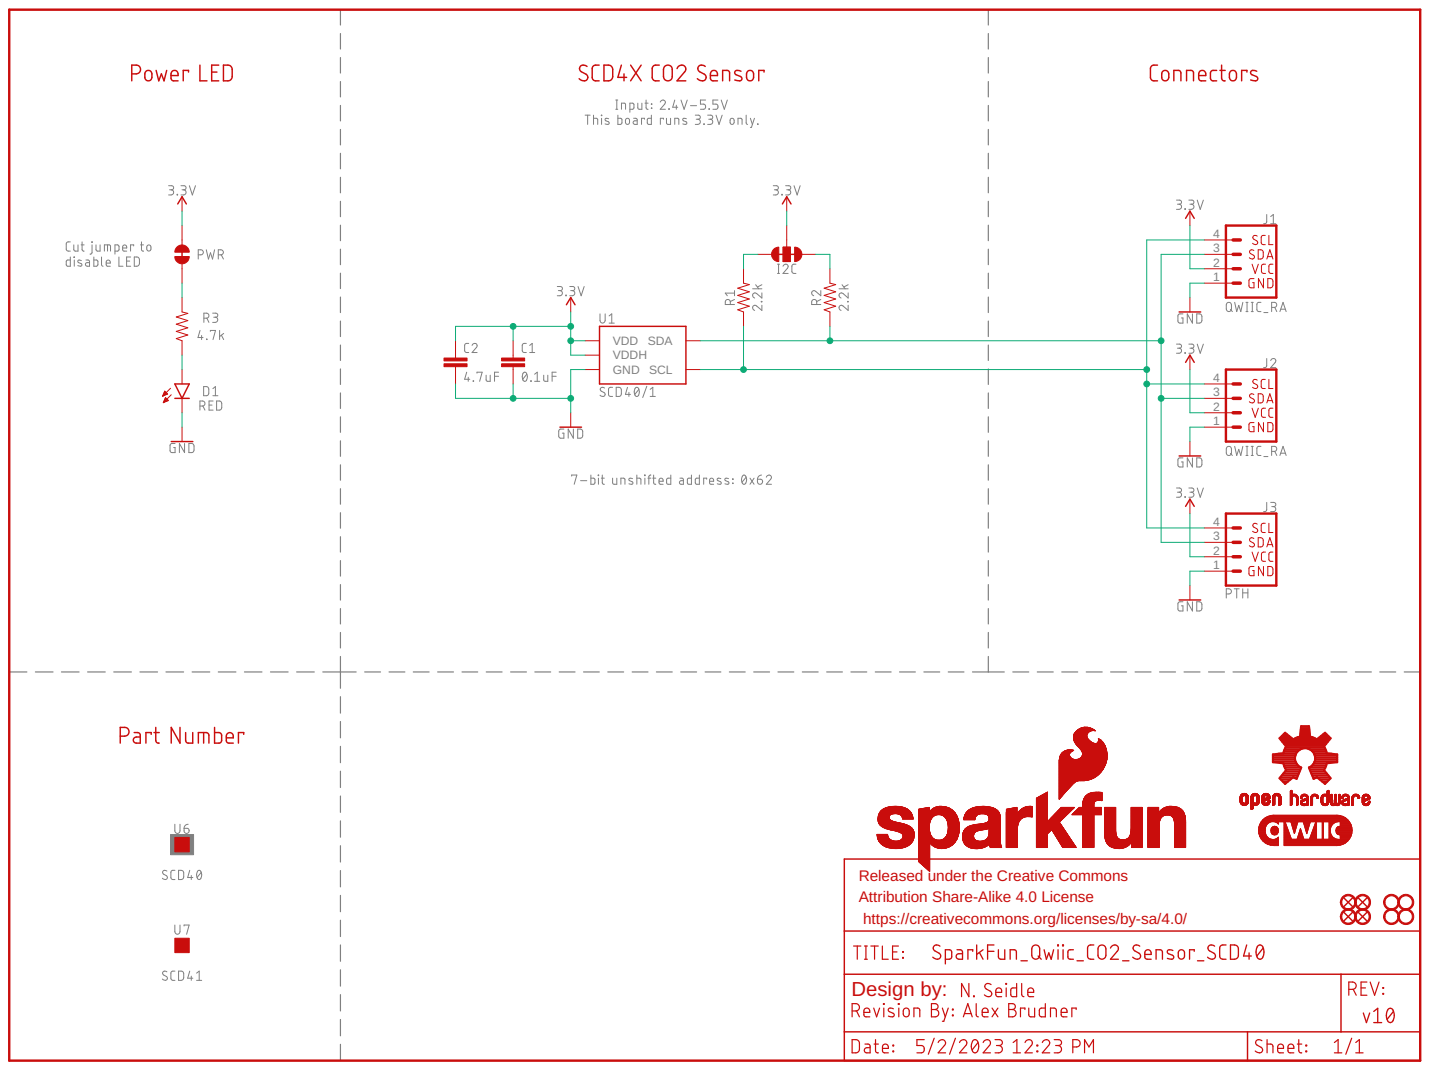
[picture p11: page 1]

Released under the Creative Commons Attribution Share-Alike 4.0 License

https://creativecommons.org/licenses/by-sa/4.0/

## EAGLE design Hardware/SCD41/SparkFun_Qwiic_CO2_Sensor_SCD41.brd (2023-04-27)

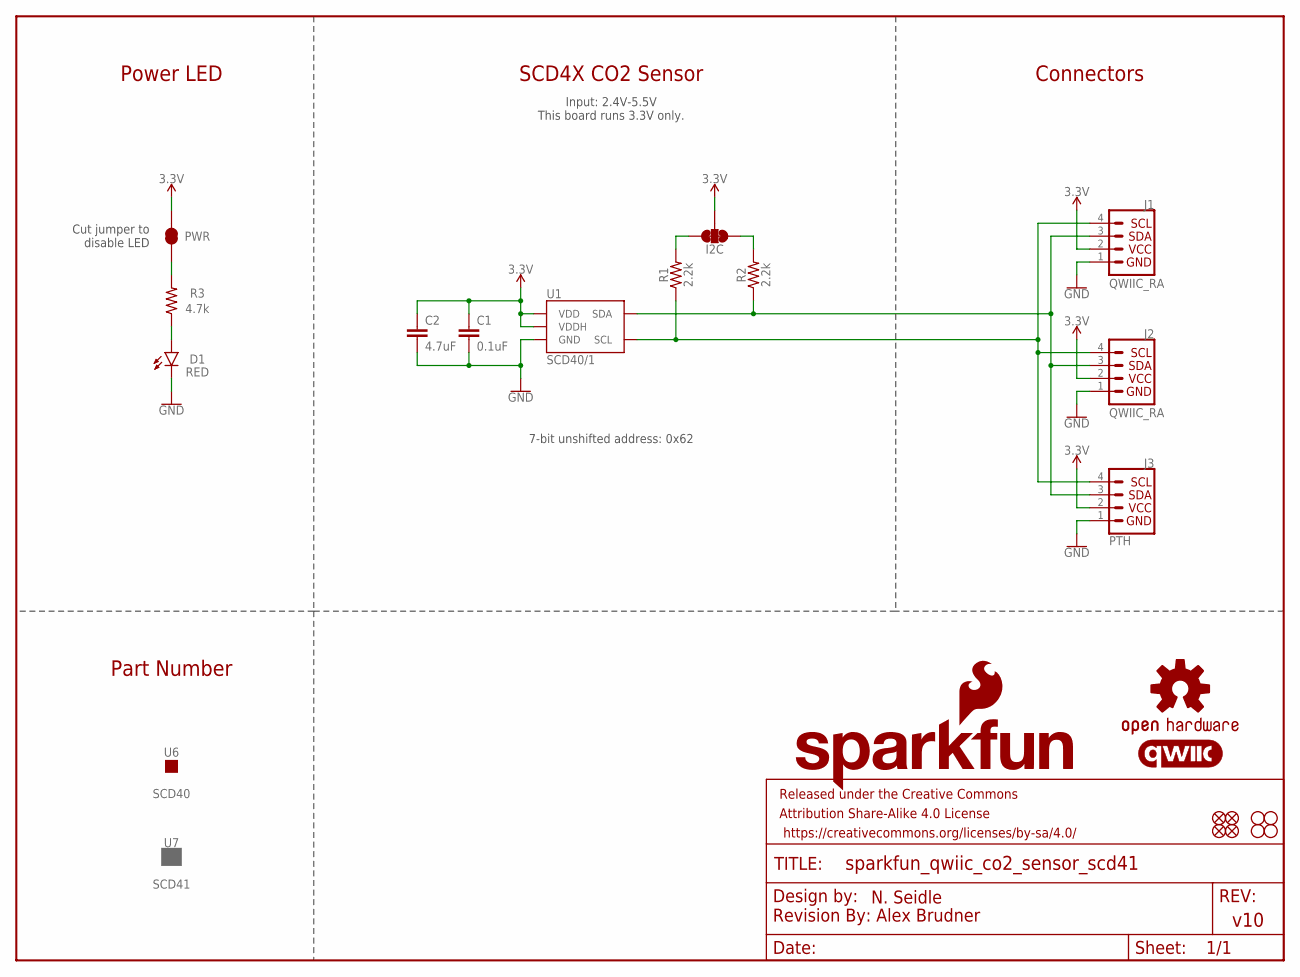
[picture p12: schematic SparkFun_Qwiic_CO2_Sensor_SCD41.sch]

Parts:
C1: 0.1uF; 0603
C2: 4.7uF; 0603
D1: RED; LED-0603
FD1, FD2, FD3, FD4: FIDUCIALUFIDUCIAL; FIDUCIAL-MICRO
FRAME1: FRAME-LETTER; CREATIVE_COMMONS
H1, H2, H3, H4: STAND-OFF
I2C: I2C; SMT-JUMPER_3_2-NC_TRACE_SILK
J1, J2: QWIIC_RA; JST04_1MM_RA
J3: PTH; 1X04_NO_SILK
LOGO1: QWIIC_LOGO_CONNECTOR; QWIIC_5.5MM
LOGO2: OSHW-LOGOS; OSHW-LOGO-S
LOGO3: SFE_LOGO_NAME_FLAMEBLANK; BLANK
PWR: PWR; SMT-JUMPER_2_NC_TRACE_SILK
R1, R2: 2.2k; 0603
R3: 4.7k; 0603
U1: SCD40/1; SCD4X
U6: SCD40; PRODUCT_IDENT_NO_NO-SILK
U7: SCD41; PRODUCT_IDENT_PASTE_NO-SILK

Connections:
3.3V: C1.1, C2.1, I2C.2, J1.2, J2.2, J3.2, PWR.2, U1.7 (VDD), U1.19 (VDDH)
GND: C1.2, C2.2, D1.C, J1.1, J2.1, J3.1, U1.6 (GND), U1.20 (GND), U1.CP (GND)
unnamed: I2C.1, R2.2
unnamed: I2C.3, R1.2
unnamed: PWR.1, R3.2
unnamed: D1.A, R3.1
SCL: J1.4, J2.4, J3.4, R1.1, U1.9 (SCL)
SDA: J1.3, J2.3, J3.3, R2.1, U1.10 (SDA)

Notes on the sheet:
Cut jumper to disable LED
SCD4X CO2 Sensor
Power LED
Connectors
Part Number
Input: 2.4V-5.5V This board runs 3.3V only.
7-bit unshifted address: 0x62

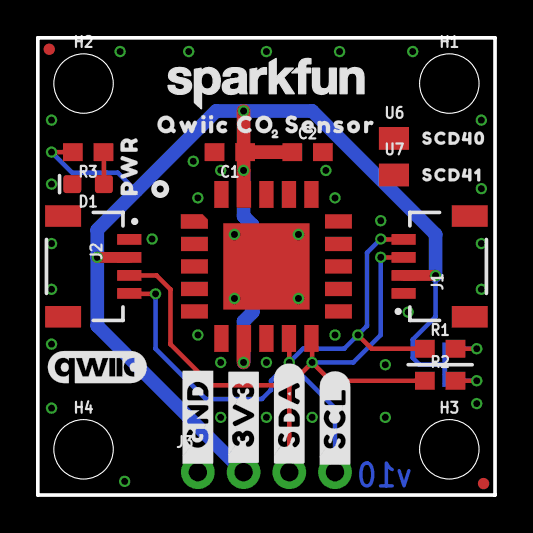
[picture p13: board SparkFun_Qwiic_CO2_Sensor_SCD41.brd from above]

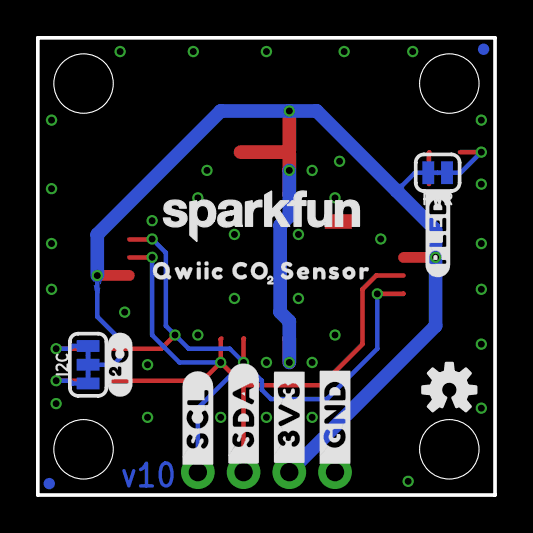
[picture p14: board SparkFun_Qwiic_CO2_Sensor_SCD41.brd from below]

Board: 2 copper layers, 25.4 x 25.4 mm, 49 parts (16 on the bottom side), 8 nets.

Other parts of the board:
U$1, U$18: #_GND#14
U$2, U$19: #_3V3#15
U$3, U$20: #_SDA#15
U$4, U$21: #_SCL#16
U$5, U$12: SFE_LOGO_NAME_.1
U$6: SCD414140404021
U$7: SCD40414140404022
U$8, U$13: QWIIC_CO0
U$9, U$14: SENSOR0
U$10, U$15: 20
U$11: SFE_LOGO_FLAME_STOP_.1
U$16: #PLED#21
U$17: #I�C#0
U$22: ORDERING_INSTRUCTIONS
U$23: PWR0

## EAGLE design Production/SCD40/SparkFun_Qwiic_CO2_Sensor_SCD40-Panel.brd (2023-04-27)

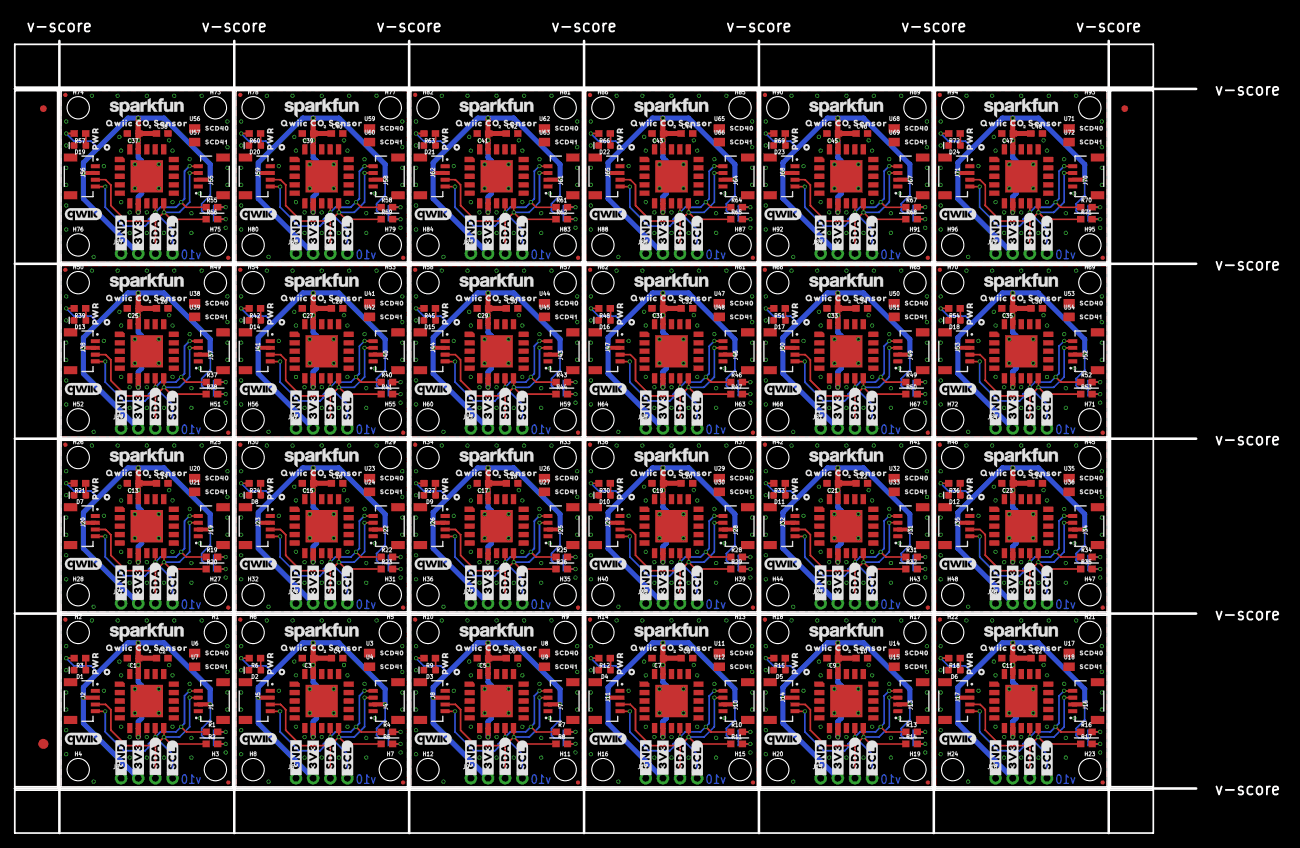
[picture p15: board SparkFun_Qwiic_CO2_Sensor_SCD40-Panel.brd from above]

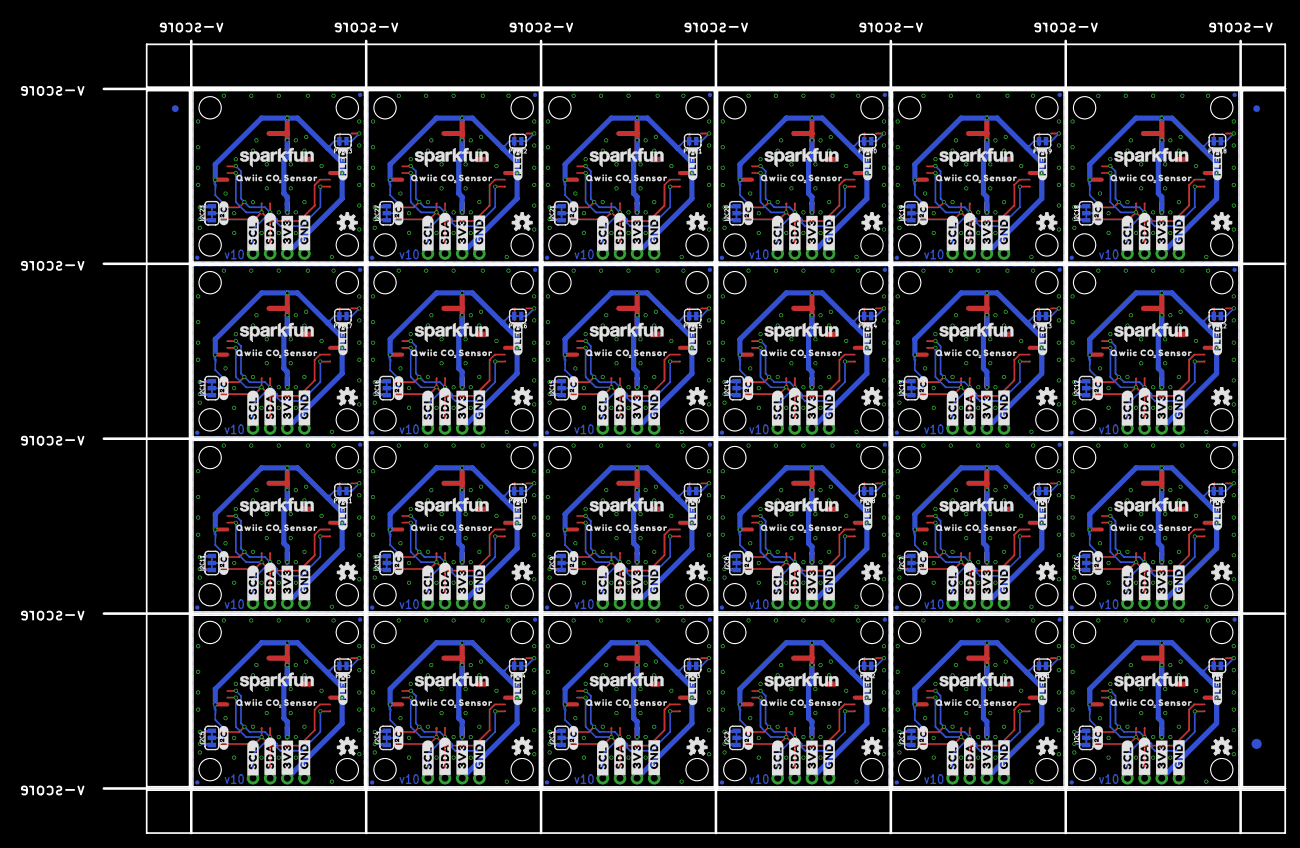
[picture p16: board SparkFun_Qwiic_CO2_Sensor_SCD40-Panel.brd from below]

Board: 2 copper layers, 175.0 x 117.3 mm, 1134 parts (387 on the bottom side), 192 nets.

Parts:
C1, C3, C5, C7, C9, C11, C13, C15, C17, C19, C21, C23, C25, C27, C29, C31, C33, C35, C37, C39, C41, C43, C45, C47: 0.1uF; 0603
C2, C4, C6, C8, C10, C12, C14, C16, C18, C20, C22, C24, C26, C28, C30, C32, C34, C36, C38, C40, C42, C44, C46, C48: 4.7uF; 0603
D1, D2, D3, D4, D5, D6, D7, D8, D9, D10, D11, D12, D13, D14, D15, D16, D17, D18, D19, D20, D21, D22, D23, D24: RED; LED-0603
E$1, E$2, E$3, E$4: FIDUCIAL-1X2
E$5, E$6: FIDUCIAL-1.5X3
FD1, FD2, FD3, FD4, FD5, FD6, FD7, FD8, FD9, FD10, FD11, FD12, FD13, FD14, FD15, FD16, FD17, FD18, FD19, FD20, FD21, FD22, FD23, FD24, FD25, FD26, FD27, FD28, FD29, FD30, FD31, FD32, FD33, FD34, FD35, FD36, FD37, FD38, FD39, FD40, FD41, FD42, FD43, FD44, FD45, FD46, FD47, FD48, FD49, FD50, FD51, FD52, FD53, FD54, FD55, FD56, FD57, FD58, FD59, FD60, FD61, FD62, FD63, FD64, FD65, FD66, FD67, FD68, FD69, FD70, FD71, FD72, FD73, FD74, FD75, FD76, FD77, FD78, FD79, FD80, FD81, FD82, FD83, FD84, FD85, FD86, FD87, FD88, FD89, FD90, FD91, FD92, FD93, FD94, FD95, FD96: FIDUCIALUFIDUCIAL; FIDUCIAL-MICRO
H1, H2, H3, H4, H5, H6, H7, H8, H9, H10, H11, H12, H13, H14, H15, H16, H17, H18, H19, H20, H21, H22, H23, H24, H25, H26, H27, H28, H29, H30, H31, H32, H33, H34, H35, H36, H37, H38, H39, H40, H41, H42, H43, H44, H45, H46, H47, H48, H49, H50, H51, H52, H53, H54, H55, H56, H57, H58, H59, H60, H61, H62, H63, H64, H65, H66, H67, H68, H69, H70, H71, H72, H73, H74, H75, H76, H77, H78, H79, H80, H81, H82, H83, H84, H85, H86, H87, H88, H89, H90, H91, H92, H93, H94, H95, H96: STAND-OFF
I2C, I2C1, I2C2, I2C3, I2C4, I2C5, I2C6, I2C7, I2C8, I2C9, I2C10, I2C11, I2C12, I2C13, I2C14, I2C15, I2C16, I2C17, I2C18, I2C19, I2C20, I2C21, I2C22, I2C23: I2C; SMT-JUMPER_3_2-NC_TRACE_SILK
J1, J2, J4, J5, J7, J8, J10, J11, J13, J14, J16, J17, J19, J20, J22, J23, J25, J26, J28, J29, J31, J32, J34, J35, J37, J38, J40, J41, J43, J44, J46, J47, J49, J50, J52, J53, J55, J56, J58, J59, J61, J62, J64, J65, J67, J68, J70, J71: QWIIC_RA; JST04_1MM_RA
J3, J6, J9, J12, J15, J18, J21, J24, J27, J30, J33, J36, J39, J42, J45, J48, J51, J54, J57, J60, J63, J66, J69, J72: PTH; 1X04_NO_SILK
LOGO1, LOGO4, LOGO7, LOGO10, LOGO13, LOGO16, LOGO19, LOGO22, LOGO25, LOGO28, LOGO31, LOGO34, LOGO37, LOGO40, LOGO43, LOGO46, LOGO49, LOGO52, LOGO55, LOGO58, LOGO61, LOGO64, LOGO67, LOGO70: QWIIC_LOGO_CONNECTOR; QWIIC_5.5MM
LOGO2, LOGO5, LOGO8, LOGO11, LOGO14, LOGO17, LOGO20, LOGO23, LOGO26, LOGO29, LOGO32, LOGO35, LOGO38, LOGO41, LOGO44, LOGO47, LOGO50, LOGO53, LOGO56, LOGO59, LOGO62, LOGO65, LOGO68, LOGO71: OSHW-LOGOS; OSHW-LOGO-S
LOGO3, LOGO6, LOGO9, LOGO12, LOGO15, LOGO18, LOGO21, LOGO24, LOGO27, LOGO30, LOGO33, LOGO36, LOGO39, LOGO42, LOGO45, LOGO48, LOGO51, LOGO54, LOGO57, LOGO60, LOGO63, LOGO66, LOGO69, LOGO72: SFE_LOGO_NAME_FLAMEBLANK; BLANK
PWR, PWR1, PWR2, PWR3, PWR4, PWR5, PWR6, PWR7, PWR8, PWR9, PWR10, PWR11, PWR12, PWR13, PWR14, PWR15, PWR16, PWR17, PWR18, PWR19, PWR20, PWR21, PWR22, PWR23: PWR; SMT-JUMPER_2_NC_TRACE_SILK
R1, R2, R4, R5, R7, R8, R10, R11, R13, R14, R16, R17, R19, R20, R22, R23, R25, R26, R28, R29, R31, R32, R34, R35, R37, R38, R40, R41, R43, R44, R46, R47, R49, R50, R52, R53, R55, R56, R58, R59, R61, R62, R64, R65, R67, R68, R70, R71: 2.2k; 0603
R3, R6, R9, R12, R15, R18, R21, R24, R27, R30, R33, R36, R39, R42, R45, R48, R51, R54, R57, R60, R63, R66, R69, R72: 4.7k; 0603
U1, U2, U5, U10, U13, U16, U19, U22, U25, U28, U31, U34, U37, U40, U43, U46, U49, U52, U55, U58, U61, U64, U67, U70: SCD40/1; SCD4X
U3, U6, U8, U11, U14, U17, U20, U23, U26, U29, U32, U35, U38, U41, U44, U47, U50, U53, U56, U59, U62, U65, U68, U71: SCD40; PRODUCT_IDENT_PASTE_NO-SILK
U4, U7, U9, U12, U15, U18, U21, U24, U27, U30, U33, U36, U39, U42, U45, U48, U51, U54, U57, U60, U63, U66, U69, U72: SCD41; PRODUCT_IDENT_NO_NO-SILK
U$1, U$18, U$22, U$39, U$45, U$61, U$67, U$83, U$89, U$105, U$111, U$127, U$133, U$149, U$155, U$171, U$177, U$193, U$199, U$215, U$221, U$237, U$243, U$259, U$265, U$281, U$287, U$303, U$309, U$325, U$331, U$347, U$353, U$369, U$375, U$391, U$397, U$413, U$419, U$435, U$441, U$457, U$463, U$479, U$485, U$501, U$507, U$523: #_GND#14
U$2, U$19, U$24, U$40, U$46, U$62, U$68, U$84, U$90, U$106, U$112, U$128, U$134, U$150, U$156, U$172, U$178, U$194, U$200, U$216, U$222, U$238, U$244, U$260, U$266, U$282, U$288, U$304, U$310, U$326, U$332, U$348, U$354, U$370, U$376, U$392, U$398, U$414, U$420, U$436, U$442, U$458, U$464, U$480, U$486, U$502, U$508, U$524: #_3V3#15
U$3, U$20, U$25, U$41, U$47, U$63, U$69, U$85, U$91, U$107, U$113, U$129, U$135, U$151, U$157, U$173, U$179, U$195, U$201, U$217, U$223, U$239, U$245, U$261, U$267, U$283, U$289, U$305, U$311, U$327, U$333, U$349, U$355, U$371, U$377, U$393, U$399, U$415, U$421, U$437, U$443, U$459, U$465, U$481, U$487, U$503, U$509, U$525: #_SDA#15
U$4, U$21, U$26, U$42, U$48, U$64, U$70, U$86, U$92, U$108, U$114, U$130, U$136, U$152, U$158, U$174, U$180, U$196, U$202, U$218, U$224, U$240, U$246, U$262, U$268, U$284, U$290, U$306, U$312, U$328, U$334, U$350, U$356, U$372, U$378, U$394, U$400, U$416, U$422, U$438, U$444, U$460, U$466, U$482, U$488, U$504, U$510, U$526: #_SCL#16
U$5, U$12, U$27, U$34, U$49, U$56, U$71, U$78, U$93, U$100, U$115, U$122, U$137, U$144, U$159, U$166, U$181, U$188, U$203, U$210, U$225, U$232, U$247, U$254, U$269, U$276, U$291, U$298, U$313, U$320, U$335, U$342, U$357, U$364, U$379, U$386, U$401, U$408, U$423, U$430, U$445, U$452, U$467, U$474, U$489, U$496, U$511, U$518: SFE_LOGO_NAME_.1
U$6, U$28, U$50, U$72, U$94, U$116, U$138, U$160, U$182, U$204, U$226, U$248, U$270, U$292, U$314, U$336, U$358, U$380, U$402, U$424, U$446, U$468, U$490, U$512: SCD414140404021
U$7, U$29, U$51, U$73, U$95, U$117, U$139, U$161, U$183, U$205, U$227, U$249, U$271, U$293, U$315, U$337, U$359, U$381, U$403, U$425, U$447, U$469, U$491, U$513: SCD40414140404022
U$8, U$13, U$30, U$35, U$52, U$57, U$74, U$79, U$96, U$101, U$118, U$123, U$140, U$145, U$162, U$167, U$184, U$189, U$206, U$211, U$228, U$233, U$250, U$255, U$272, U$277, U$294, U$299, U$316, U$321, U$338, U$343, U$360, U$365, U$382, U$387, U$404, U$409, U$426, U$431, U$448, U$453, U$470, U$475, U$492, U$497, U$514, U$519: QWIIC_CO0
U$9, U$14, U$31, U$36, U$53, U$58, U$75, U$80, U$97, U$102, U$119, U$124, U$141, U$146, U$163, U$168, U$185, U$190, U$207, U$212, U$229, U$234, U$251, U$256, U$273, U$278, U$295, U$300, U$317, U$322, U$339, U$344, U$361, U$366, U$383, U$388, U$405, U$410, U$427, U$432, U$449, U$454, U$471, U$476, U$493, U$498, U$515, U$520: SENSOR0
U$10, U$15, U$32, U$37, U$54, U$59, U$76, U$81, U$98, U$103, U$120, U$125, U$142, U$147, U$164, U$169, U$186, U$191, U$208, U$213, U$230, U$235, U$252, U$257, U$274, U$279, U$296, U$301, U$318, U$323, U$340, U$345, U$362, U$367, U$384, U$389, U$406, U$411, U$428, U$433, U$450, U$455, U$472, U$477, U$494, U$499, U$516, U$521: 20
U$11, U$33, U$55, U$77, U$99, U$121, U$143, U$165, U$187, U$209, U$231, U$253, U$275, U$297, U$319, U$341, U$363, U$385, U$407, U$429, U$451, U$473, U$495, U$517: SFE_LOGO_FLAME_STOP_.1
U$16, U$38, U$60, U$82, U$104, U$126, U$148, U$170, U$192, U$214, U$236, U$258, U$280, U$302, U$324, U$346, U$368, U$390, U$412, U$434, U$456, U$478, U$500, U$522: #PLED#21
U$17, U$43, U$65, U$87, U$109, U$131, U$153, U$175, U$197, U$219, U$241, U$263, U$285, U$307, U$329, U$351, U$373, U$395, U$417, U$439, U$461, U$483, U$505, U$527: #I�C#0
U$23, U$44, U$66, U$88, U$110, U$132, U$154, U$176, U$198, U$220, U$242, U$264, U$286, U$308, U$330, U$352, U$374, U$396, U$418, U$440, U$462, U$484, U$506, U$528: PWR0

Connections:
3.3V: C1.1, C2.1, I2C.2, J1.2, J2.2, J3.2, PWR.2, U1.7, U1.19
3.3V1: C3.1, C4.1, I2C1.2, J4.2, J5.2, J6.2, PWR1.2, U2.7, U2.19
3.3V2: C5.1, C6.1, I2C2.2, J7.2, J8.2, J9.2, PWR2.2, U5.7, U5.19
3.3V3: C7.1, C8.1, I2C3.2, J10.2, J11.2, J12.2, PWR3.2, U10.7, U10.19
3.3V4: C9.1, C10.1, I2C4.2, J13.2, J14.2, J15.2, PWR4.2, U13.7, U13.19
3.3V5: C11.1, C12.1, I2C5.2, J16.2, J17.2, J18.2, PWR5.2, U16.7, U16.19
3.3V6: C13.1, C14.1, I2C6.2, J19.2, J20.2, J21.2, PWR6.2, U19.7, U19.19
3.3V7: C15.1, C16.1, I2C7.2, J22.2, J23.2, J24.2, PWR7.2, U22.7, U22.19
3.3V8: C17.1, C18.1, I2C8.2, J25.2, J26.2, J27.2, PWR8.2, U25.7, U25.19
3.3V9: C19.1, C20.1, I2C9.2, J28.2, J29.2, J30.2, PWR9.2, U28.7, U28.19
3.3V10: C21.1, C22.1, I2C10.2, J31.2, J32.2, J33.2, PWR10.2, U31.7, U31.19
3.3V11: C23.1, C24.1, I2C11.2, J34.2, J35.2, J36.2, PWR11.2, U34.7, U34.19
3.3V12: C25.1, C26.1, I2C12.2, J37.2, J38.2, J39.2, PWR12.2, U37.7, U37.19
3.3V13: C27.1, C28.1, I2C13.2, J40.2, J41.2, J42.2, PWR13.2, U40.7, U40.19
3.3V14: C29.1, C30.1, I2C14.2, J43.2, J44.2, J45.2, PWR14.2, U43.7, U43.19
3.3V15: C31.1, C32.1, I2C15.2, J46.2, J47.2, J48.2, PWR15.2, U46.7, U46.19
3.3V16: C33.1, C34.1, I2C16.2, J49.2, J50.2, J51.2, PWR16.2, U49.7, U49.19
3.3V17: C35.1, C36.1, I2C17.2, J52.2, J53.2, J54.2, PWR17.2, U52.7, U52.19
3.3V18: C37.1, C38.1, I2C18.2, J55.2, J56.2, J57.2, PWR18.2, U55.7, U55.19
3.3V19: C39.1, C40.1, I2C19.2, J58.2, J59.2, J60.2, PWR19.2, U58.7, U58.19
3.3V20: C41.1, C42.1, I2C20.2, J61.2, J62.2, J63.2, PWR20.2, U61.7, U61.19
3.3V21: C43.1, C44.1, I2C21.2, J64.2, J65.2, J66.2, PWR21.2, U64.7, U64.19
3.3V22: C45.1, C46.1, I2C22.2, J67.2, J68.2, J69.2, PWR22.2, U67.7, U67.19
3.3V23: C47.1, C48.1, I2C23.2, J70.2, J71.2, J72.2, PWR23.2, U70.7, U70.19
GND: C1.2, C2.2, D1.C, J1.1, J2.1, J3.1, U1.6, U1.20, U1.CP
GND1: C3.2, C4.2, D2.C, J4.1, J5.1, J6.1, U2.6, U2.20, U2.CP
GND2: C5.2, C6.2, D3.C, J7.1, J8.1, J9.1, U5.6, U5.20, U5.CP
GND3: C7.2, C8.2, D4.C, J10.1, J11.1, J12.1, U10.6, U10.20, U10.CP
GND4: C9.2, C10.2, D5.C, J13.1, J14.1, J15.1, U13.6, U13.20, U13.CP
GND5: C11.2, C12.2, D6.C, J16.1, J17.1, J18.1, U16.6, U16.20, U16.CP
GND6: C13.2, C14.2, D7.C, J19.1, J20.1, J21.1, U19.6, U19.20, U19.CP
GND7: C15.2, C16.2, D8.C, J22.1, J23.1, J24.1, U22.6, U22.20, U22.CP
GND8: C17.2, C18.2, D9.C, J25.1, J26.1, J27.1, U25.6, U25.20, U25.CP
GND9: C19.2, C20.2, D10.C, J28.1, J29.1, J30.1, U28.6, U28.20, U28.CP
GND10: C21.2, C22.2, D11.C, J31.1, J32.1, J33.1, U31.6, U31.20, U31.CP
GND11: C23.2, C24.2, D12.C, J34.1, J35.1, J36.1, U34.6, U34.20, U34.CP
GND12: C25.2, C26.2, D13.C, J37.1, J38.1, J39.1, U37.6, U37.20, U37.CP
GND13: C27.2, C28.2, D14.C, J40.1, J41.1, J42.1, U40.6, U40.20, U40.CP
GND14: C29.2, C30.2, D15.C, J43.1, J44.1, J45.1, U43.6, U43.20, U43.CP
GND15: C31.2, C32.2, D16.C, J46.1, J47.1, J48.1, U46.6, U46.20, U46.CP
GND16: C33.2, C34.2, D17.C, J49.1, J50.1, J51.1, U49.6, U49.20, U49.CP
GND17: C35.2, C36.2, D18.C, J52.1, J53.1, J54.1, U52.6, U52.20, U52.CP
GND18: C37.2, C38.2, D19.C, J55.1, J56.1, J57.1, U55.6, U55.20, U55.CP
GND19: C39.2, C40.2, D20.C, J58.1, J59.1, J60.1, U58.6, U58.20, U58.CP
GND20: C41.2, C42.2, D21.C, J61.1, J62.1, J63.1, U61.6, U61.20, U61.CP
GND21: C43.2, C44.2, D22.C, J64.1, J65.1, J66.1, U64.6, U64.20, U64.CP
GND22: C45.2, C46.2, D23.C, J67.1, J68.1, J69.1, U67.6, U67.20, U67.CP
GND23: C47.2, C48.2, D24.C, J70.1, J71.1, J72.1, U70.6, U70.20, U70.CP
unnamed: I2C1.1, R5.2
unnamed: I2C1.3, R4.2
unnamed: I2C.1, R2.2
unnamed: I2C.3, R1.2
unnamed: PWR.1, R3.2
unnamed: D1.A, R3.1
unnamed: PWR1.1, R6.2
unnamed: D2.A, R6.1
unnamed: I2C2.1, R8.2
unnamed: I2C2.3, R7.2
unnamed: PWR2.1, R9.2
unnamed: D3.A, R9.1
unnamed: I2C3.1, R11.2
unnamed: I2C3.3, R10.2
unnamed: PWR3.1, R12.2
unnamed: D4.A, R12.1
unnamed: I2C4.1, R14.2
unnamed: I2C4.3, R13.2
unnamed: PWR4.1, R15.2
unnamed: D5.A, R15.1
unnamed: I2C5.1, R17.2
unnamed: I2C5.3, R16.2
unnamed: PWR5.1, R18.2
unnamed: D6.A, R18.1
unnamed: I2C6.1, R20.2
unnamed: I2C6.3, R19.2
unnamed: PWR6.1, R21.2
unnamed: D7.A, R21.1
unnamed: I2C7.1, R23.2
unnamed: I2C7.3, R22.2
unnamed: PWR7.1, R24.2
unnamed: D8.A, R24.1
unnamed: I2C8.1, R26.2
unnamed: I2C8.3, R25.2
unnamed: PWR8.1, R27.2
unnamed: D9.A, R27.1
unnamed: I2C9.1, R29.2
unnamed: I2C9.3, R28.2
unnamed: PWR9.1, R30.2
unnamed: D10.A, R30.1
unnamed: I2C10.1, R32.2
unnamed: I2C10.3, R31.2
unnamed: PWR10.1, R33.2
unnamed: D11.A, R33.1
unnamed: I2C11.1, R35.2
unnamed: I2C11.3, R34.2
unnamed: PWR11.1, R36.2
unnamed: D12.A, R36.1
unnamed: I2C12.1, R38.2
unnamed: I2C12.3, R37.2
unnamed: PWR12.1, R39.2
unnamed: D13.A, R39.1
unnamed: I2C13.1, R41.2
unnamed: I2C13.3, R40.2
unnamed: PWR13.1, R42.2
unnamed: D14.A, R42.1
unnamed: I2C14.1, R44.2
unnamed: I2C14.3, R43.2
unnamed: PWR14.1, R45.2
unnamed: D15.A, R45.1
unnamed: I2C15.1, R47.2
unnamed: I2C15.3, R46.2
unnamed: PWR15.1, R48.2
unnamed: D16.A, R48.1
unnamed: I2C16.1, R50.2
unnamed: I2C16.3, R49.2
unnamed: PWR16.1, R51.2
unnamed: D17.A, R51.1
unnamed: I2C17.1, R53.2
unnamed: I2C17.3, R52.2
unnamed: PWR17.1, R54.2
unnamed: D18.A, R54.1
unnamed: I2C18.1, R56.2
unnamed: I2C18.3, R55.2
unnamed: PWR18.1, R57.2
unnamed: D19.A, R57.1
unnamed: I2C19.1, R59.2
unnamed: I2C19.3, R58.2
unnamed: PWR19.1, R60.2
unnamed: D20.A, R60.1
unnamed: I2C20.1, R62.2
unnamed: I2C20.3, R61.2
unnamed: PWR20.1, R63.2
unnamed: D21.A, R63.1
unnamed: I2C21.1, R65.2
unnamed: I2C21.3, R64.2
unnamed: PWR21.1, R66.2
unnamed: D22.A, R66.1
unnamed: I2C22.1, R68.2
unnamed: I2C22.3, R67.2
unnamed: PWR22.1, R69.2
unnamed: D23.A, R69.1
unnamed: I2C23.1, R71.2
unnamed: I2C23.3, R70.2
unnamed: PWR23.1, R72.2
unnamed: D24.A, R72.1
SCL: J1.4, J2.4, J3.4, R1.1, U1.9
SCL1: J4.4, J5.4, J6.4, R4.1, U2.9
SCL2: J7.4, J8.4, J9.4, R7.1, U5.9
SCL3: J10.4, J11.4, J12.4, R10.1, U10.9
SCL4: J13.4, J14.4, J15.4, R13.1, U13.9
SCL5: J16.4, J17.4, J18.4, R16.1, U16.9
SCL6: J19.4, J20.4, J21.4, R19.1, U19.9
SCL7: J22.4, J23.4, J24.4, R22.1, U22.9
SCL8: J25.4, J26.4, J27.4, R25.1, U25.9
SCL9: J28.4, J29.4, J30.4, R28.1, U28.9
SCL10: J31.4, J32.4, J33.4, R31.1, U31.9
SCL11: J34.4, J35.4, J36.4, R34.1, U34.9
SCL12: J37.4, J38.4, J39.4, R37.1, U37.9
SCL13: J40.4, J41.4, J42.4, R40.1, U40.9
SCL14: J43.4, J44.4, J45.4, R43.1, U43.9
SCL15: J46.4, J47.4, J48.4, R46.1, U46.9
SCL16: J49.4, J50.4, J51.4, R49.1, U49.9
SCL17: J52.4, J53.4, J54.4, R52.1, U52.9
SCL18: J55.4, J56.4, J57.4, R55.1, U55.9
SCL19: J58.4, J59.4, J60.4, R58.1, U58.9
SCL20: J61.4, J62.4, J63.4, R61.1, U61.9
SCL21: J64.4, J65.4, J66.4, R64.1, U64.9
SCL22: J67.4, J68.4, J69.4, R67.1, U67.9
SCL23: J70.4, J71.4, J72.4, R70.1, U70.9
SDA: J1.3, J2.3, J3.3, R2.1, U1.10
SDA1: J4.3, J5.3, J6.3, R5.1, U2.10
SDA2: J7.3, J8.3, J9.3, R8.1, U5.10
SDA3: J10.3, J11.3, J12.3, R11.1, U10.10
SDA4: J13.3, J14.3, J15.3, R14.1, U13.10
SDA5: J16.3, J17.3, J18.3, R17.1, U16.10
SDA6: J19.3, J20.3, J21.3, R20.1, U19.10
SDA7: J22.3, J23.3, J24.3, R23.1, U22.10
SDA8: J25.3, J26.3, J27.3, R26.1, U25.10
SDA9: J28.3, J29.3, J30.3, R29.1, U28.10
SDA10: J31.3, J32.3, J33.3, R32.1, U31.10
SDA11: J34.3, J35.3, J36.3, R35.1, U34.10
SDA12: J37.3, J38.3, J39.3, R38.1, U37.10
SDA13: J40.3, J41.3, J42.3, R41.1, U40.10
SDA14: J43.3, J44.3, J45.3, R44.1, U43.10
SDA15: J46.3, J47.3, J48.3, R47.1, U46.10
SDA16: J49.3, J50.3, J51.3, R50.1, U49.10
SDA17: J52.3, J53.3, J54.3, R53.1, U52.10
SDA18: J55.3, J56.3, J57.3, R56.1, U55.10
SDA19: J58.3, J59.3, J60.3, R59.1, U58.10
SDA20: J61.3, J62.3, J63.3, R62.1, U61.10
SDA21: J64.3, J65.3, J66.3, R65.1, U64.10
SDA22: J67.3, J68.3, J69.3, R68.1, U67.10
SDA23: J70.3, J71.3, J72.3, R71.1, U70.10

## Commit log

2023-04-26 Added schematic/board files
    Added panels.
    Added Lib with part.
    [SparkFun_Qwiic_CO2_Sensor_SCD40-Panel.GBL, SparkFun_Qwiic_CO2_Sensor_SCD40-Panel.GBO, SparkFun_Qwiic_CO2_Sensor_SCD40-Panel.GBP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]
2023-04-27 Update from pre-design review notes.
    Changed I2C PURs from 4.7k to 2.2k to match Qwiic standards.
    Changed wording on revision.
    Update top stop of pin 1 of sensor.
    Repanelize.
    [SparkFun_Qwiic_CO2_Sensor_SCD40-Panel.brd, SparkFun_Qwiic_CO2_Sensor_SCD40.brd, SparkFun_Qwiic_CO2_Sensor_SCD40.sch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]
2023-06-07 Final Review and Image Update
    Final review with minor fixes. Adding Arduino screenshots.

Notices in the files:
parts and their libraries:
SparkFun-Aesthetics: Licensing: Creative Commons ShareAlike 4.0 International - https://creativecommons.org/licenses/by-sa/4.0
